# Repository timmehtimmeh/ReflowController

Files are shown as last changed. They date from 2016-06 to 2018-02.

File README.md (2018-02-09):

# TimmehTimmeh's Arduino Board

This repository contains support for the following TimmehTimmeh Arduino-compatible reflow oven controller.  The reflow controller runs on an Atmega32u4 at 3.3V/8MHz.

# Attributions
This project is based on TMK's headless reflow oven (https://github.com/tmk/HeadlessReflowOven) which is in turn based on  work of 

* [ohararp ReflowOven]  (https://github.com/ohararp/ReflowOven)

* which is modification of [rocketscream Reflow-Oven-Controller]  (https://github.com/rocketscream/Reflow-Oven-Controller)

rocketscream released the work under Creative Commons Share Alike v3.0 license.

The bootloader and corresponding installation instructions are a modification of Sparkfun's bootloader code for their Arduino Pro Micro: (https://github.com/sparkfun/Arduino_Boards)

The directory structure is as follows:
* [ReflowBoard]	- The firmware, bootloader, and arduino IDE files that communicate with the board
* [ReflowOven]	- The software (arduino software project) that runs on the board
* [Schematics] - schematics and eagle files for the board
* [libraries] - Library files that the arduino project links against

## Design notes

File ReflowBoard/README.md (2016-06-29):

# TimmehTimmeh's Arduino Board

This repository contains support for the following TimmehTimmeh Arduino-compatible development boards:

#### AVR Boards

* [Tim's Reflow Board]

Each board will be added as an entry to the Arduino **Tools** > **Board** menu.

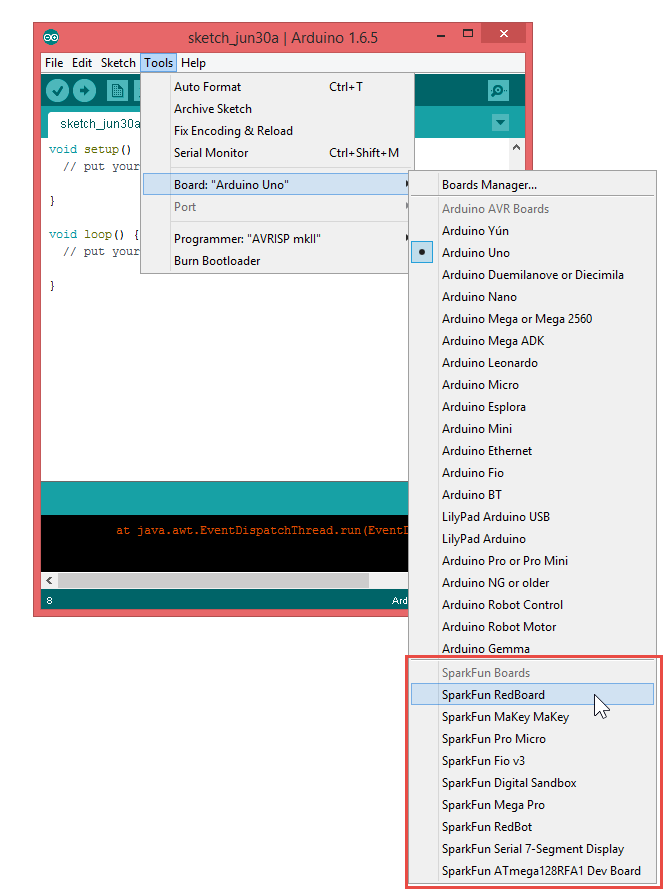
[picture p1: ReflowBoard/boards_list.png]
Example image


### Installation Instructions

To add board support for our products, go to **File** > **Preferences**, and paste this URL into the 'Additional Boards Manager URLs' input field:

	https://raw.githubusercontent.com/timmehtimmeh/ReflowController/master/ReflowBoard/IDE_Board_Manager/package_TimmehTimmeh_index.json

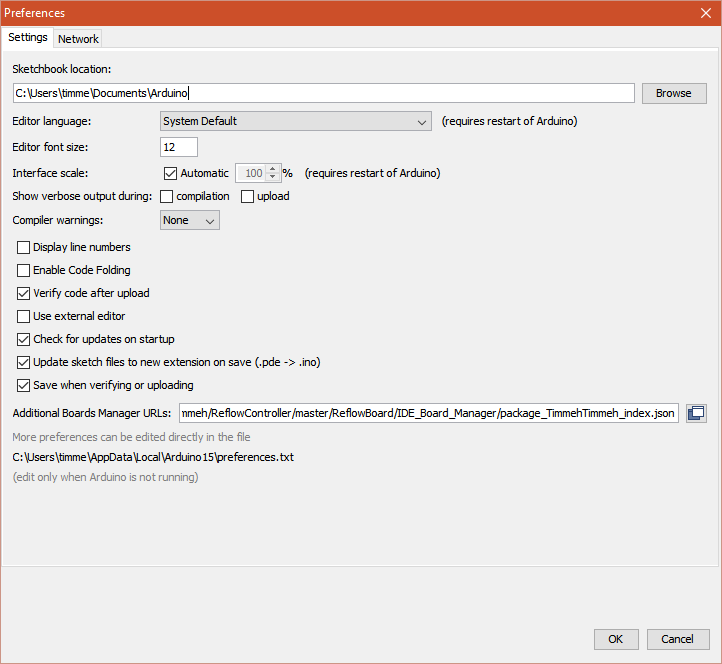
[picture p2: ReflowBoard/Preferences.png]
Adding a board manager list


This field can be found in 'Preferences...' under the Arduino File menu.

Now, under the **Tools** > **Board** > **Boards Manager...**, if you type in "TimmehTimmeh", you will see an option to install board files for the reflow controller board. Click "Install" to add these to your list.

**NOTE: If you are using Arduino 1.6.6 and the link isn't working for you, change "https" at the beginning of the link to "http" and try again. We're working to figure out why this is happening in version 1.6.6.**

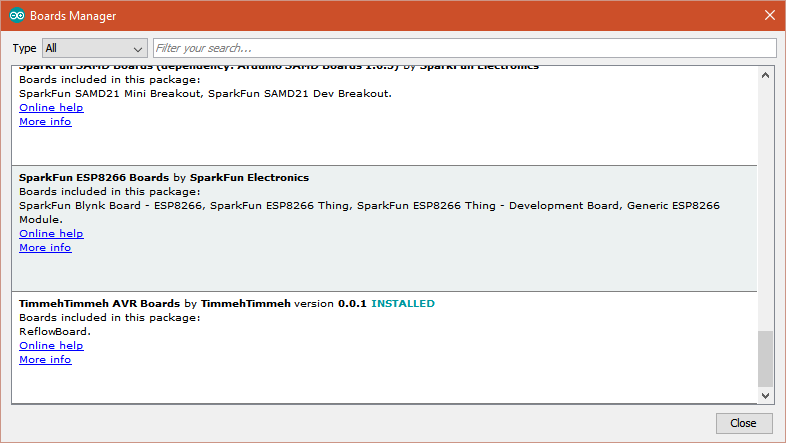
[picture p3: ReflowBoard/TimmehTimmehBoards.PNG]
TimmehTimmeh Boards image


Now, when you select the Boards list, you will see a collection of new boards for Timmeh.

### Flashing the bootloader

To flash the bootloader, power up the board with either the onboard USB or the 2.1mm jack, and plug the board into a AVRISP MKII via the icsp port

In Atmel Studio 
Set the fuses to the  following values:
* low_fuses = 0xFF
* high_fuses = 0xD8
* extended _fuses = 0xFE

### Notes

* **Please note: This will only work under Arduino IDE versions 1.5 and up.**
* Information on compiling and programming the bootloaders can be found in the bootloaders directory.

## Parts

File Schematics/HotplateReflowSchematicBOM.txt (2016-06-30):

Partlist exported from C:/Users/timme/Documents/Arduino/ReflowController/Schematics/HotplateReflowSchematic.sch at 6/29/2016 9:49 PM

Qty Value                        Device                       Package                     Parts                              Description                                                                              MF MPN     OC_FARNELL OC_NEWARK PROD_ID   
1                                LEDCHIP-LED0603              CHIP-LED0603                PWR                                LED                                                                                                                                
1                                M06LOCK                      1X06_LOCK                   JP2                                Header 6                                                                                                                           
1   .1u                          CAP0603-CAP                  0603-CAP                    C7                                 Capacitor                                                                                                                          
1   10k                          RESISTOR0603                 0603-RES                    R6                                 Resistor                                                                                                                           
8   10k                          RESISTOR0603-RES             0603-RES                    R3, R5, R8, R9, R10, R11, R12, R13 Resistor                                                                                                                           
1   10k                          TRIMPOT                      TRIMPOT-5MM-V2              R4                                 Various small potentiometers for "set-and-forget" applications                                                                     
2   10u                          CAP0603-CAP                  0603-CAP                    C2, C10                            Capacitor                                                                                                                          
1   1k                           RESISTOR0603                 0603-RES                    R7                                 Resistor                                                                                                                           
5   1u                           CAP0603-CAP                  0603-CAP                    C1, C3, C4, C8, C9                 Capacitor                                                                                                                          
1   2.1MMJACKTHM                 2.1MMJACKTHM                 PJ-102A                     U$3                                2.1mm x 5.5mm THM DC jack with internal switch. Digikey part #PJ-102A, 4UCON part #05537                                           
2   22                           RESISTOR0603-RES             0603-RES                    R1, R2                             Resistor                                                                                                                           
2   22pF                         CAP0603-CAP                  0603-CAP                    C5, C6                             Capacitor                                                                                                                          
1   47u                          CAP0603-CAP                  0603-CAP                    C11                                Capacitor                                                                                                                          
1   500mA                        PTCFUSE-1812                 1812                        F1                                 PTC fuses, resettable thermistors                                                                                                  
1   8Mhz                         CRYSTALHC49UP                HC49UP                      Q1                                 CRYSTAL                                                                                             unknown    unknown             
1   ATMEGA32U4TQFP               ATMEGA32U4TQFP               SPARKFUN-DIGITALIC_TQFP44   U$1                                Atmel 44-pin 8-bit Microcontroller with 32KBytes of ISP Flash and USB Controller -----                                   IC-11161  
1   JS5208                       JS5208                       JS5208_PKG                  U$2                                                                                                                                                                   
1   JTAG                         M03X2SHROUD                  2X3-SHROUDED                JP1                                2x3 .1" header.                                                                                                          CONN-10681
1   LCD-16X2SILK                 LCD-16X2SILK                 LCD-16X2                    U1                                 Standard text-only 16x2 parallel input LCD                                                                                         
1   LM358D                       LM358D                       SO08                        IC4                                OP AMP also LM158; LM258; LM2904                                                                                                   
1   MAX31855                     MAX31855                     SOIC8                       IC1                                                                                                                                                                   
1   P-CHANNEL-MOSFET-SOT23-3     P-CHANNEL-MOSFET-SOT23-3     SOT23-3                     U$5                                P-Channel MOSFET Mode Field Effect Transistor                                                                                      
2   REG1117                      REG1117                      SOT223                      IC2, IC3                           800mA and 1A Low Dropout (LDO) Positive Regulator                                           REG1117 1097566    14P6981             
2   STANDOFF_ELECTRICAL          STANDOFF_ELECTRICAL          STANDOFF-ELECTRICAL         S2, S4                             A standoff intended to be an electrically connected point.                                                                         
1   SWITCH-MOMENTARY-2SMD-1101NE SWITCH-MOMENTARY-2SMD-1101NE TACTILE-SWITCH-1101NE       S1                                 Various NO switches- pushbuttons, reed, etc                                                                              SWCH-00815
1   Therm                        M022.54MM_SCREWTERM          1X02_2.54_SCREWTERM         JP3                                Standard 2-pin 0.1" header. Use with                                                                                               
1   USB-CON-5PIN-105017-0001     USB-CON-5PIN-105017-0001     USB-MICRO-MOLEX-105017-0001 U$4                                Molex Micro USB 105017-0001

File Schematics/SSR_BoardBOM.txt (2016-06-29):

Partlist exported from C:/Users/timme/Documents/Arduino/ReflowController/Schematics/SSR_Board.sch at 6/28/2016 10:34 PM

Qty Value       Device                Package               Parts              Description                    PROD_ID     VALUE
1               M03SCREW              SCREWTERMINAL-3.5MM-3 JP2                Header 3                                        
1   100         RESISTOR0603-RES      0603-RES              R6                 Resistor                                        
1   10k         RESISTOR0603-RES      0603-RES              R8                 Resistor                                        
1   220         RESISTOR0603-RES      0603-RES              R7                 Resistor                                        
1   2N3904      TRANSISTOR_NPNSOT23-3 SOT23-3               Q2                 Generic NPN BJT                TRANS-08049      
1   330         RESISTOR0603-RES      0603-RES              R5                 Resistor                                        
1   6PCV-02-006 6PCV-02-006           6PCV-02-006           U$2                TE-Connectivity-AMP-Connectors                  
1   GREEN       LED-GREEN0603         LED-0603              D1                 Various green LEDs             DIO-00821   GREEN
1   S108T02     RELAY-SOLIDSTATEPTH   RELAY-S108T02         U1                                                                 
4   STAND-OFF   STAND-OFF             STAND-OFF             U$3, U$4, U$5, U$7 Stand Off

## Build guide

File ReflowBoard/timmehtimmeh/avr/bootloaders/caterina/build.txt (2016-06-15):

make clean
make PID=0x9209 F_CPU=16000000
copy Caterina.hex Caterina-wiflyin.hex
make clean
make PID=0x9207 F_CPU=8000000
copy Caterina.hex Caterina-lilypadusb.hex
make clean
make PID=0x9205 F_CPU=16000000
copy Caterina.hex Caterina-promicro16.hex
make clean
make PID=0x9203 F_CPU=8000000
copy Caterina.hex Caterina-promicro8.hex 
make clean
make PID=0x2B74 F_CPU=16000000
copy Caterina.hex Caterina-makey.hex
make clean
make PID=0xF100 F_CPU=8000000
copy Caterina.hex Caterina-fio.hex
make clean
make PID=0x920B F_CPU=16000000
copy Caterina.hex Caterina-minibench.hex

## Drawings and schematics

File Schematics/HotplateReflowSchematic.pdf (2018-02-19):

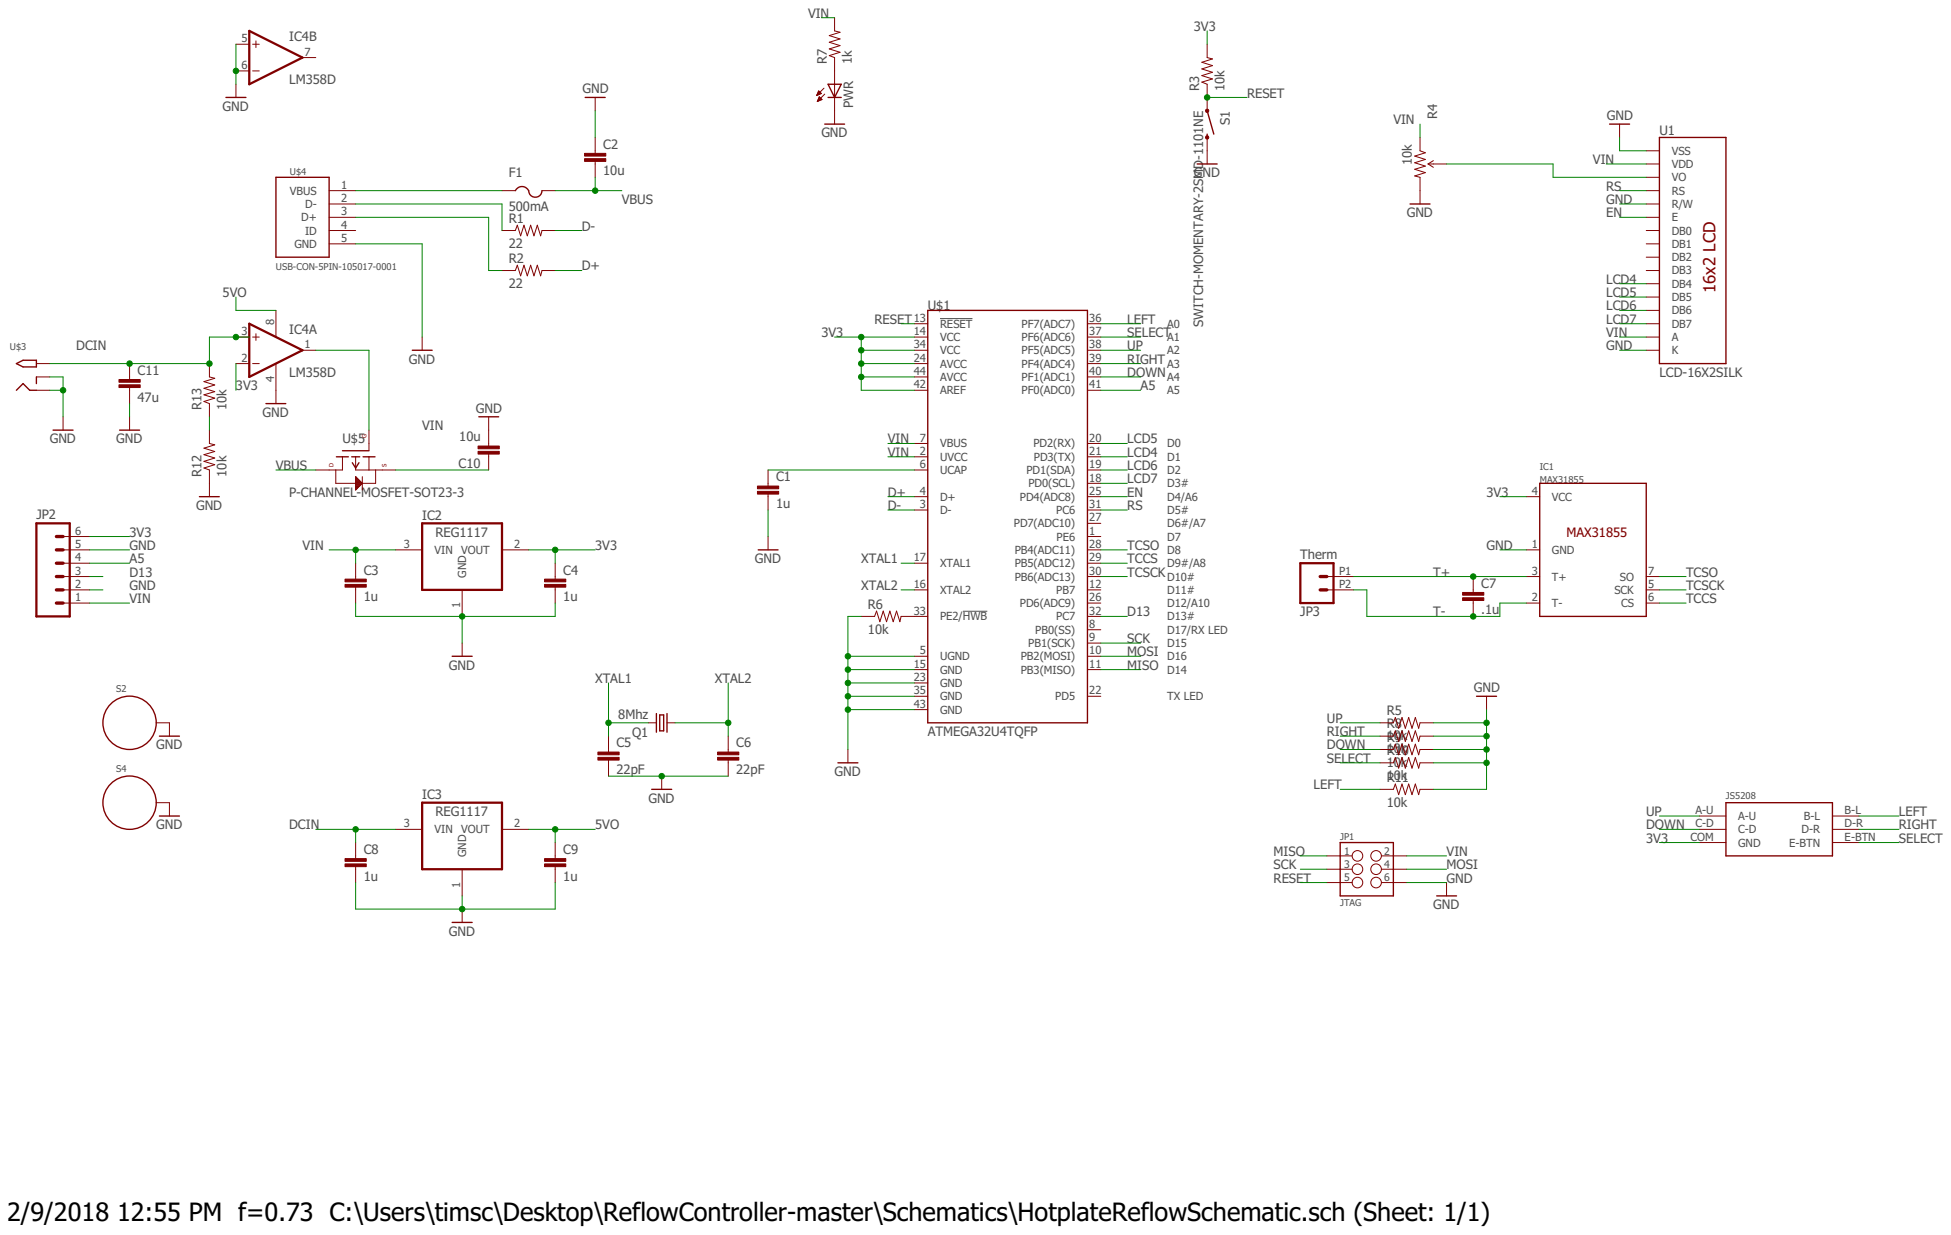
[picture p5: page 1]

2/9/2018 12:55 PM f=0.73 C:\Users\timsc\Desktop\ReflowController-master\Schematics\HotplateReflowSchematic.sch (Sheet: 1/1)

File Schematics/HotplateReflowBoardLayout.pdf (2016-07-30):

1
500mA MAX3185 | REG¹¹¹⁷

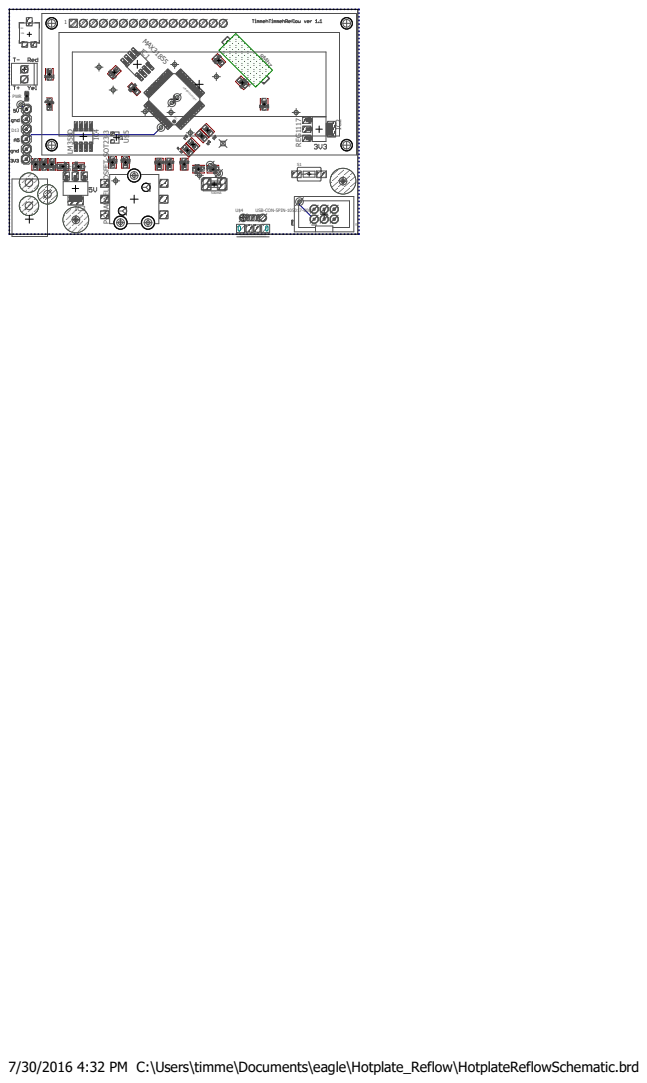
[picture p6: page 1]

8Mhz 10k ATMEGA32U4TQFP USB-CON-5PIN-105017-0001 P-CHANNEL-MOSFET-SOT23-3 LM358D

PCB EDGE CONNECTOR FRONT INTERFACE

7/30/2016 4:32 PM C:\Users\timme\Documents\eagle\Hotplate_Reflow\HotplateReflowSchematic.brd

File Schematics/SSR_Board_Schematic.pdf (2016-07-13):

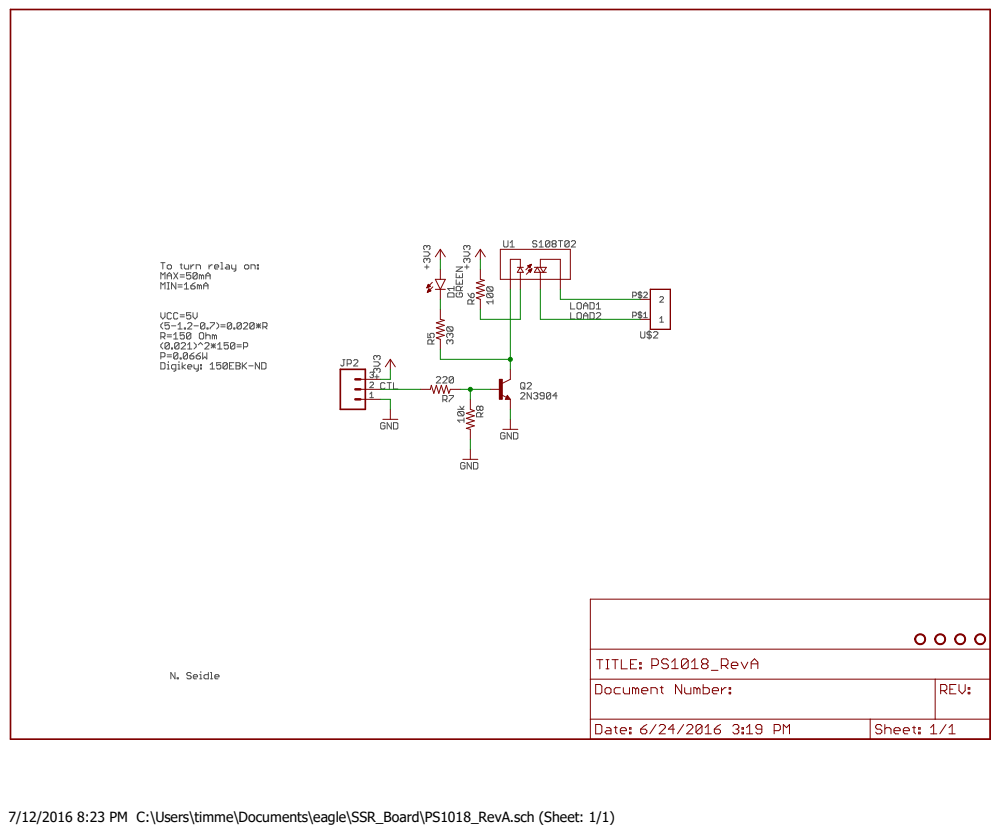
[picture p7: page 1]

7/12/2016 8:23 PM C:\Users\timme\Documents\eagle\SSR_Board\PS1018_RevA.sch (Sheet: 1/1)

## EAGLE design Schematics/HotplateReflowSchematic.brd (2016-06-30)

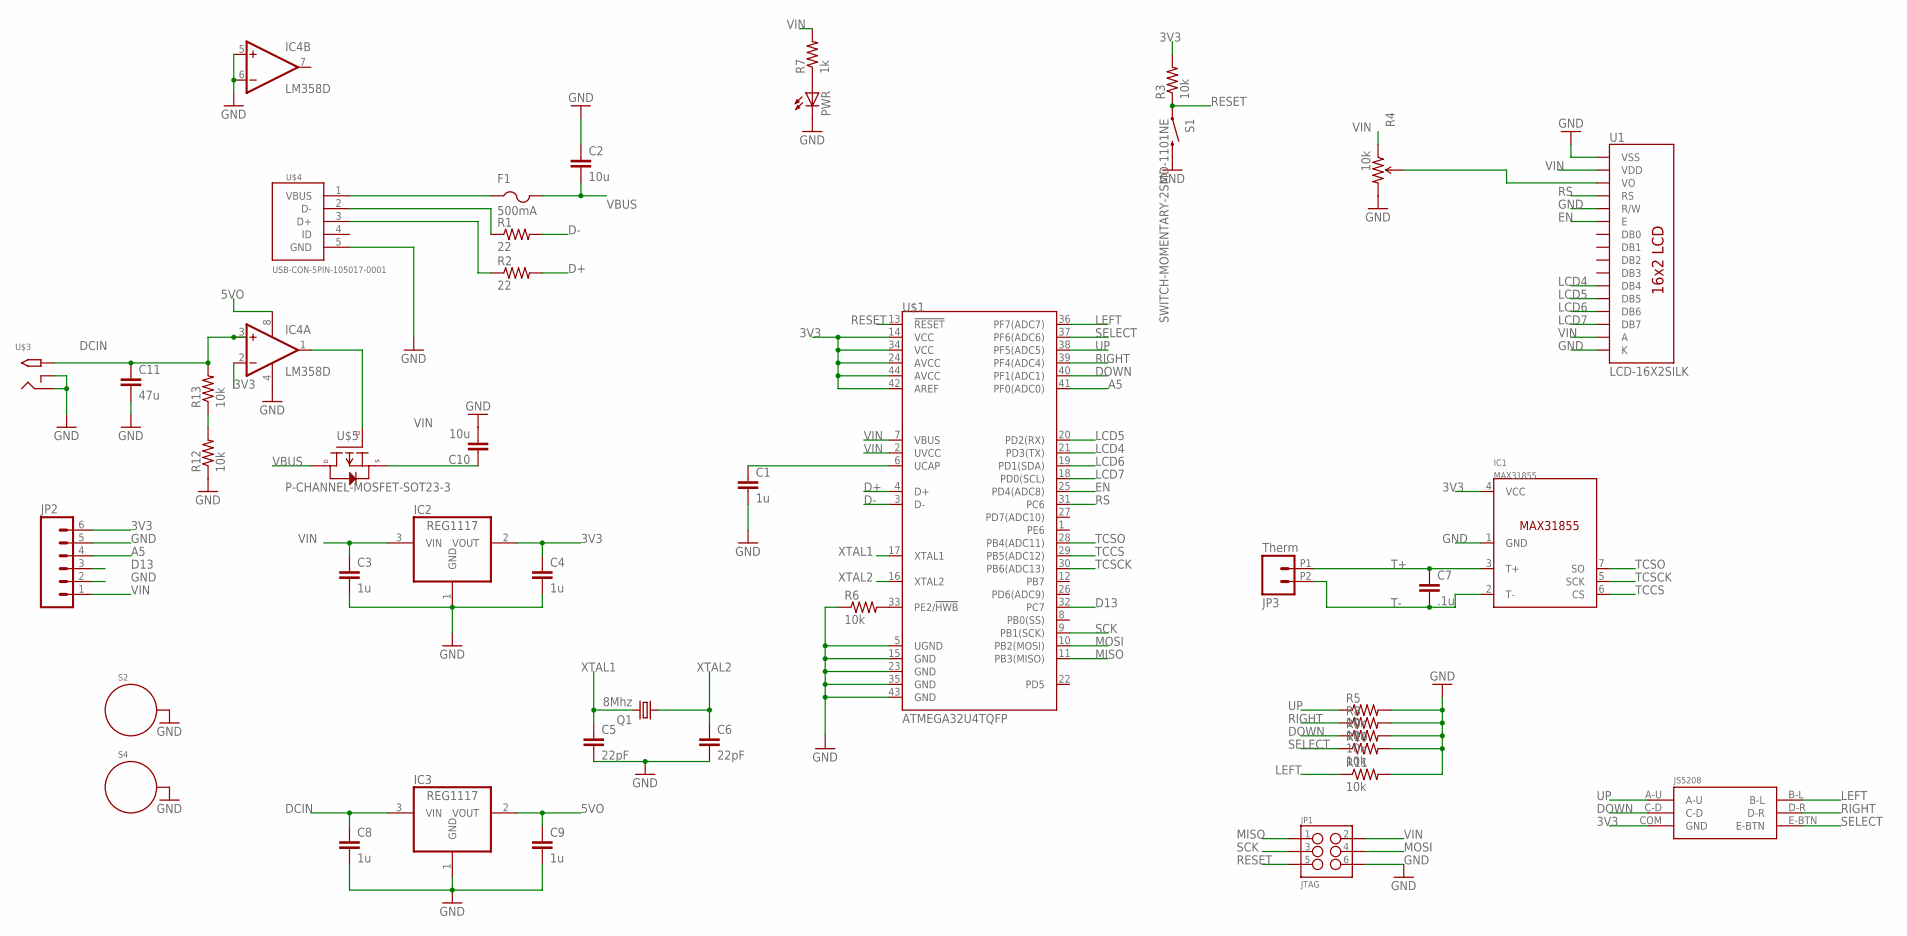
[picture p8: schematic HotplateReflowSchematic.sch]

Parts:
C1, C3, C4, C8, C9: 1u; 0603-CAP
C2, C10: 10u; 0603-CAP
C5, C6: 22pF; 0603-CAP
C7: .1u; 0603-CAP
C11: 47u; 0603-CAP
F1: 500mA; 1812
IC1: MAX31855; SOIC8
IC2, IC3: REG1117; SOT223
IC4: LM358D; SO08
JP1: JTAG; 2X3-SHROUDED
JP2: M06LOCK; 1X06_LOCK
JP3: Therm; 1X02_2.54_SCREWTERM
PWR: LEDCHIP-LED0603; CHIP-LED0603
Q1: 8Mhz; HC49UP
R1, R2: 22; 0603-RES
R3, R5, R6, R8, R9, R10, R11, R12, R13: 10k; 0603-RES
R4: 10k; TRIMPOT-5MM-V2
R7: 1k; 0603-RES
S1: SWITCH-MOMENTARY-2SMD-1101NE; TACTILE-SWITCH-1101NE
S2, S4: STANDOFF_ELECTRICAL; STANDOFF-ELECTRICAL
U1: LCD-16X2SILK; LCD-16X2
U$1: ATMEGA32U4TQFP; SPARKFUN-DIGITALIC_TQFP44
U$2: JS5208; JS5208_PKG
U$3: 2.1MMJACKTHM; PJ-102A
U$4: USB-CON-5PIN-105017-0001; USB-MICRO-MOLEX-105017-0001
U$5: P-CHANNEL-MOSFET-SOT23-3; SOT23-3

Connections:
3V3: C4.1, IC1.4 (VCC), IC2.2 (VOUT), IC4.2 (-IN), JP2.6, R3.2, U$1.14 (VCC), U$1.24 (AVCC), U$1.34 (VCC), U$1.42 (AREF), U$1.44 (AVCC), U$2.COM (GND)
5VO: C9.1, IC3.2 (VOUT), IC4.8 (V+)
A5: JP2.4, U$1.41 (PF0(ADC0))
D13: JP2.3, U$1.32 (PC7)
D+: R2.2, U$1.4 (D+)
D-: R1.2, U$1.3 (D-)
DCIN: C8.1, C11.1, IC3.3 (VIN), IC4.3 (+IN), R13.2, U$3.TIP
DOWN: R9.1, U$1.40 (PF1(ADC1)), U$2.C-D
EN: U1.6 (E), U$1.25 (PD4(ADC8))
GND: C1.2, C2.1, C3.2, C4.2, C5.2, C6.2, C8.2, C9.2, C10.2, C11.2, IC1.1 (GND), IC2.1 (GND), IC3.1 (GND), IC4.4 (V-), IC4.5 (+IN), IC4.6 (-IN), JP1.6, JP2.2, JP2.5, PWR.C, R4.C (CW), R5.2, R6.1, R8.2, R9.2, R10.2, R11.2, R12.1, S1.2, S2.P1, S4.P1, U1.1 (VSS), U1.5 (R/W), U1.16 (K), U$1.5 (UGND), U$1.15 (GND), U$1.23 (GND), U$1.35 (GND), U$1.43 (GND), U$3.RING, U$3.RING_SW, U$4.5 (GND)
LCD4: U1.11 (DB4), U$1.21 (PD3(TX))
LCD5: U1.12 (DB5), U$1.20 (PD2(RX))
LCD6: U1.13 (DB6), U$1.19 (PD1(SDA))
LCD7: U1.14 (DB7), U$1.18 (PD0(SCL))
LEFT: R11.1, U$1.36 (PF7(ADC7)), U$2.B-L
MISO: JP1.1, U$1.11 (PB3(MISO))
MOSI: JP1.4, U$1.10 (PB2(MOSI))
unnamed: R4.B (WIPER), U1.3 (VO)
unnamed: F1.1, U$4.1 (VBUS)
unnamed: R1.1, U$4.2 (D-)
unnamed: R2.1, U$4.3 (D+)
unnamed: C1.1, U$1.6 (UCAP)
unnamed: PWR.A, R7.1
unnamed: R6.2, U$1.33 (PE2/!HWB)
unnamed: R12.2, R13.1
unnamed: IC4.1 (OUT), U$5.1 (G)
RESET: JP1.5, R3.1, S1.1, U$1.13 (!RESET)
RIGHT: R8.1, U$1.39 (PF4(ADC4)), U$2.D-R
RS: U1.4 (RS), U$1.31 (PC6)
SCK: JP1.3, U$1.9 (PB1(SCK))
SELECT: R10.1, U$1.37 (PF6(ADC6)), U$2.E-BTN
T+: C7.1, IC1.3 (T+), JP3.P1 (1)
T-: C7.2, IC1.2 (T-), JP3.P2 (2)
TCCS: IC1.6 (CS), U$1.29 (PB5(ADC12))
TCSCK: IC1.5 (SCK), U$1.30 (PB6(ADC13))
TCSO: IC1.7 (SO), U$1.28 (PB4(ADC11))
UP: R5.1, U$1.38 (PF5(ADC5)), U$2.A-U
VBUS: C2.2, F1.2, U$5.3 (D)
VIN: C3.1, C10.1, IC2.3 (VIN), JP1.2, JP2.1, R4.A (CCW), R7.2, U1.2 (VDD), U1.15 (A), U$1.2 (UVCC), U$1.7 (VBUS), U$5.2 (S)
XTAL1: C5.1, Q1.2, U$1.17 (XTAL1)
XTAL2: C6.1, Q1.1, U$1.16 (XTAL2)

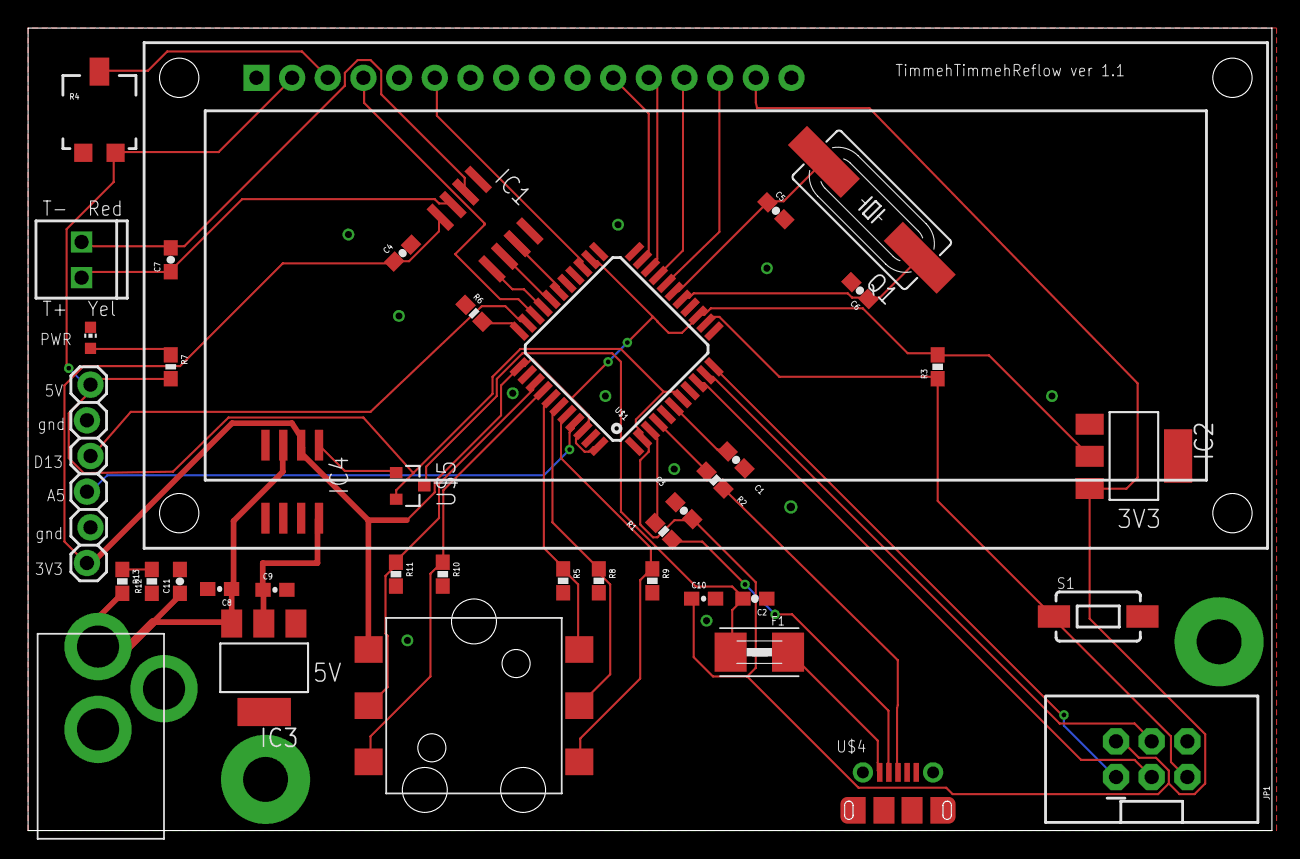
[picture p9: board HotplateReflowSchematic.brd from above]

Board: 2 copper layers, 88.6 x 57.1 mm, 43 parts (0 on the bottom side), 41 nets.

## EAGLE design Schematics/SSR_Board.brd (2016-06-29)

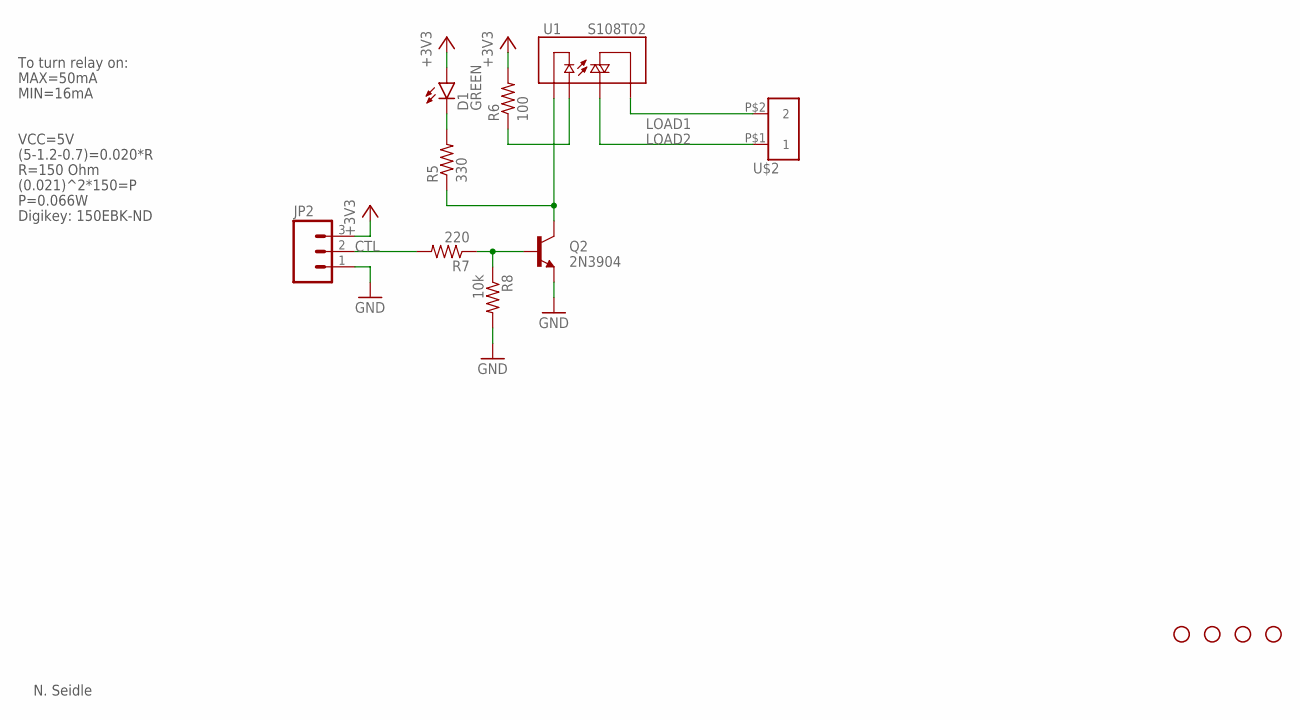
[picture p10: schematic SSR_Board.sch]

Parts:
D1: GREEN; LED-0603
JP2: M03SCREW; SCREWTERMINAL-3.5MM-3
Q2: 2N3904; SOT23-3
R5: 330; 0603-RES
R6: 100; 0603-RES
R7: 220; 0603-RES
R8: 10k; 0603-RES
U1: S108T02; RELAY-S108T02
U$2: 6PCV-02-006
U$3, U$4, U$5, U$7: STAND-OFF

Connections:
+3V3: D1.A, JP2.3, R6.2
COIL: Q2.3 (C), R5.1, U1.4 (-)
CTL: JP2.2, R7.2
GND: JP2.1, Q2.2 (E), R8.2
LOAD1: U1.1 (T1), U$2.P$2 (2)
LOAD2: U1.2 (T2), U$2.P$1 (1)
unnamed: R6.1, U1.3 (+)
unnamed: Q2.1 (B), R7.1, R8.1
unnamed: D1.C, R5.2

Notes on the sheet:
N. Seidle
To turn relay on:
(5-1.2-0.7)=0.020*R
R=150 Ohm
VCC=5V
MAX=50mA
MIN=16mA
(0.021)^2*150=P
P=0.066W
Digikey: 150EBK-ND

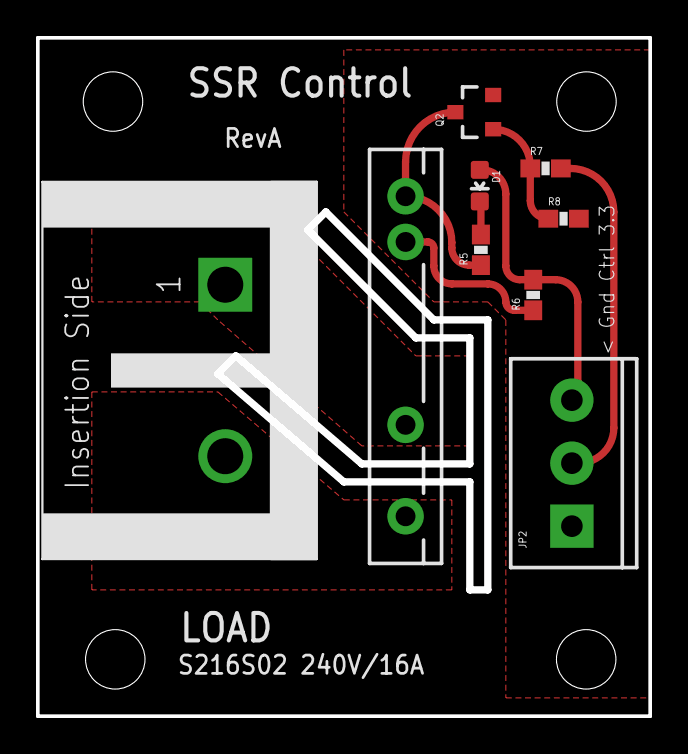
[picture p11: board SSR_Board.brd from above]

Board: 2 copper layers, 34.0 x 37.7 mm, 13 parts (0 on the bottom side), 9 nets.

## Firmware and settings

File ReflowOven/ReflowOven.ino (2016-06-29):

/*********************************************************************
  Headless ReflowController - just with button, buzzer and LED

  based on ReflowOven
    https://github.com/ohararp/ReflowOven

  - To start/abort reflow process push button.
  - Buzzer beeps when cooling stage starts and ends. You may open door oven to cool quickly.
  - LED and buzzer are optional but buzzer is recommended.
  - Using with KOIZUMI Wide Oven Toaster 1200W KOS-1202
**********************************************************************/
// Includes
#include <Adafruit_MAX31855.h>  // Thermocouple Library - https://github.com/rocketscream/MAX31855
#include <PID_v1.h>             // PID Library - http://playground.arduino.cc/Code/PIDLibrary
//             - https://github.com/br3ttb/Arduino-PID-Library/
#include <LiquidCrystal.h>


typedef enum REFLOW_STATE
{
  REFLOW_STATE_IDLE,
  REFLOW_STATE_PREHEAT,
  REFLOW_STATE_SOAK,
  REFLOW_STATE_REFLOW,
  REFLOW_STATE_COOL,
  REFLOW_STATE_COMPLETE,
  REFLOW_STATE_TOO_HOT,
  REFLOW_STATE_ERROR,
  REFLOW_STATE_ABORT
} reflowState_t;

typedef enum REFLOW_STATUS
{
  REFLOW_STATUS_OFF,
  REFLOW_STATUS_ON
} reflowStatus_t;

typedef enum MENU_STATE
{
  MENU_START_SELECTED,
  MENU_PREHEAT_PARAMS_SELECTED,
  MENU_SET_PREHEAT_PARAMS,
  MENU_SOAK_PARAMS_SELECTED,
  MENU_SET_SOAK_PARAMS,
  MENU_REFLOW_PARAMS_SELECTED,
  MENU_SET_REFLOW_PARAMS,
  MENU_COOL_PARAMS_SELECTED,
  MENU_SET_COOL_PARAMS,
  MENU_STATE_REFLOWING
} menuState_t;


/*  Reflow temperature profile

    Tamura leaded SOLDER PASTE(Sn62.8 Pb36.8 Ag0.4) Reflow Profile
        |
    220-|                                                  x  x
        |                                                x       x
    200-|                                               x           x
        |                                              x|           |
        |                                            x  |           | x
    170-|                              x x x  x x  x    |           |   x
        |                  x  x  x  x           |       |<- 20-60s->|     x
    150-|               x                       |                   |
        |             x |                       |                   |
        |           x   |                       |                   |
        |         x     |                       |                   |
        |       x       |                       |                   |
        |     x         |                       |                   |
        |   x   <3C/s   |        20C/60s        |         20/20s    |
    30 -| x             |                       |                   |
        |     <60s      |<-        60s        ->|                   |
        |     Preheat   |        Soaking        |       Reflow      |   Cool
     0  |_ _ _ _ _ _ _ _|_ _ _ _ _ _ _ _ _ _ _ _|_ _ _ _ _ _ _ _ _ _|_ _ _ _
*/
float TEMPERATURE_COOL       = 100;
float TEMPERATURE_SOAK_MIN   = 150;
float TEMPERATURE_SOAK_MAX   = 170;
float TEMPERATURE_REFLOW_MAX = 230;

// Preheat: 1.5C/s
#define PREHEAT_TEMPERATURE_STEP    15
#define PREHEAT_MS_STEP             10000

// Soak: 20C/60s
#define SOAK_TEMPERATURE_STEP       2
#define SOAK_MS_STEP                6000

// Reflow: 20C/20s
#define REFLOW_TEMPERATURE_STEP     5
#define REFLOW_MS_STEP              5000


// ***** PID PARAMETERS *****
// ***** PRE-HEAT STAGE *****
float PID_KP_PREHEAT         = 300;
float PID_KI_PREHEAT         = 0.05;
float PID_KD_PREHEAT         = 350;
// ***** SOAKING STAGE *****
float PID_KP_SOAK            = 300;
float PID_KI_SOAK            = 0.05;
float PID_KD_SOAK            = 350;
// ***** REFLOW STAGE *****
float PID_KP_REFLOW          = 300;
float PID_KI_REFLOW          = 0.05;
float PID_KD_REFLOW          = 350;

#define PID_SAMPLE_TIME        1000
#define SENSOR_SAMPLING_TIME   1000


// Reflow status strings
const char* ssdMessagesReflowStatus[] = {
  "  Ready  ",
  " Preheat ",
  "   Soak  ",
  "  Reflow ",
  "   Cool  ",
  " Complete",
  "  !HOT!  ",
  "  Error  "
};


//
// Pin Definitions
//

int noPin = -1;
int upPin = A2;
int downPin = A4;
int leftPin = A0;
int rightPin = A3;
int selectPin = A1;

int HeaterPin = 13;
int SSRPin1 = A5;

int thermocoupleCLKPin = 10;
int thermocoupleSOPin  = 8;
int thermocoupleCSPin  = 9;

LiquidCrystal lcd(5, 4, 1, 0, 2, 3);

// ***** PID CONTROL VARIABLES *****
double setpoint;
double input;
double inputOld; //Store old Temperature

double output;
double kp = PID_KP_PREHEAT;
double ki = PID_KI_PREHEAT;
double kd = PID_KD_PREHEAT;
int windowSize;
unsigned long windowStartTime;
unsigned long nextCheck;
unsigned long nextRead;
unsigned long timerSoak;
unsigned long buzzerPeriod;
boolean StartTest;

// Reflow oven controller state machine state variable
reflowState_t reflowState;
// Reflow oven controller status
reflowStatus_t reflowStatus;

menuState_t menuState;

//Button Variables
byte ButtCount  = 0;

// tc Error Counter
int tcErrorCtr = 0;

// Seconds timer
int timerSeconds;

// Library Setup
// Specify PID control interface
PID reflowOvenPID(&input, &output, &setpoint, kp, ki, kd, DIRECT);
Adafruit_MAX31855 thermocouple(thermocoupleCLKPin, thermocoupleCSPin, thermocoupleSOPin);

// Setup
void setup()   {
  // Setup Serial Baudrate
  Serial.begin(57600);

  // set up the LCD's number of columns and rows:
  lcd.begin(16, 2);
  lcd.print("Hello World");

  // initialize the Led pin as an output.
  //pinMode(Led, OUTPUT);

  // Init Buttons
  // pinMode(selectPin, INPUT_PULLUP);

  // Init Elements
  pinMode(HeaterPin, OUTPUT);
  //pinMode(BuzPin, OUTPUT);

  digitalWrite(HeaterPin, LOW);
  //digitalWrite(BuzPin, LOW);

  //button pin setup
  pinMode(selectPin, INPUT);
  pinMode(upPin, INPUT);
  pinMode(downPin, INPUT);
  pinMode(leftPin, INPUT);
  pinMode(rightPin, INPUT);

  //output pins to control relay
  //pinMode(SSRPin0, OUTPUT);
  pinMode(SSRPin1, OUTPUT);

  // Set window size
  windowSize = 5000;
  // Initialize time keeping variable
  nextCheck = millis();
  // Initialize thermocouple reading variable
  nextRead = millis();
  // Set Relow Status = OFF
  reflowStatus = REFLOW_STATUS_OFF;
  menuState = MENU_START_SELECTED;

  StartTest = false;
}

void PrintMenuOptions(bool leftPin, bool rightPin, bool upPin, bool downPin, bool selectPin) {

  Serial.print(leftPin);
  Serial.print(rightPin);
  Serial.print(upPin);
  Serial.print(downPin);
  Serial.println(selectPin);

  //  MENU_START_SELECTED,
  //  MENU_PREHEAT_PARAMS_SELECTED,
  //  MENU_SET_PREHEAT_PARAMS,
  //  MENU_SOAK_PARAMS_SELECTED,
  //  MENU_SET_SOAK_PARAMS,
  //  MENU_REFLOW_PARAMS_SELECTED,
  //  MENU_SET_REFLOW_PARAMS,
  //  MENU_COOL_PARAMS_SELECTED,
  //  MENU_SET_COOL_PARAMS,
  //  MENU_STATE_REFLOWING

  if (millis() > nextRead)
  {
    // Read thermocouple next sampling period
    nextRead += SENSOR_SAMPLING_TIME;
    input = thermocouple.readCelsius();
    lcd.setCursor(11, 1);
    lcd.print(input);
  }
  switch (menuState)
  {

    case MENU_START_SELECTED:
      lcd.setCursor(0, 0);
      lcd.print("Cool >Start  Preheat");

      if (leftPin) {
        menuState = MENU_COOL_PARAMS_SELECTED;
      } else if (rightPin) {
        menuState = MENU_PREHEAT_PARAMS_SELECTED;
      }
      else if (selectPin) {
        menuState = MENU_STATE_REFLOWING;
        StartTest = true;
      }
      break;
    case MENU_PREHEAT_PARAMS_SELECTED:
      lcd.setCursor(0, 0);
      lcd.print("Start >Preheat  Soak");

      if (leftPin) {
        menuState = MENU_START_SELECTED;
      } else if (rightPin) {
        menuState = MENU_SOAK_PARAMS_SELECTED;
      } else if (selectPin || upPin || downPin) {
        menuState = MENU_SET_PREHEAT_PARAMS;
      }
      //      else if (upPin || downPin) {
      //        menuState = MENU_START_SELECTED;
      //      }

      break;
    case MENU_SOAK_PARAMS_SELECTED:
      lcd.setCursor(0, 0);
      lcd.print("Preheat >Soak Reflow");

      if (leftPin) {
        menuState = MENU_PREHEAT_PARAMS_SELECTED;
      } else if (rightPin) {
        menuState = MENU_REFLOW_PARAMS_SELECTED;
      } else if (selectPin || upPin || downPin) {
        menuState = MENU_SET_SOAK_PARAMS;
      }
      //      else if (upPin || downPin) {
      //        menuState = MENU_START_SELECTED;
      //      }
      break;
    case MENU_REFLOW_PARAMS_SELECTED:
      lcd.setCursor(0, 0);
      lcd.print("Soak >Reflow Cool");

      if (leftPin) {
        menuState = MENU_SOAK_PARAMS_SELECTED;
      } else if (rightPin) {
        menuState = MENU_COOL_PARAMS_SELECTED;
      } else if (selectPin || upPin || downPin) {
        menuState = MENU_SET_REFLOW_PARAMS;
      }
      //      else if (upPin || downPin) {
      //        menuState = MENU_START_SELECTED;
      //      }
      break;
    case MENU_COOL_PARAMS_SELECTED:
      lcd.setCursor(0, 0);
      lcd.print("Reflow >Cool  Start");

      if (leftPin) {
        menuState = MENU_REFLOW_PARAMS_SELECTED;
      } else if (rightPin) {
        menuState = MENU_START_SELECTED;
      } else if (selectPin || upPin || downPin) {
        menuState = MENU_SET_COOL_PARAMS;
      }
      //      else if (upPin || downPin) {
      //        menuState = MENU_START_SELECTED;
      //      }
      break;

    //TEMP SETTINGS
    //        float TEMPERATURE_COOL       = 100;
    //        float TEMPERATURE_SOAK_MIN   = 150;
    //        float TEMPERATURE_SOAK_MAX   = 170;
    //        float TEMPERATURE_REFLOW_MAX = 230;

    case MENU_SET_PREHEAT_PARAMS:
      lcd.setCursor(0, 0);
      lcd.print("Preheat Max     Curr");
      lcd.setCursor(0, 1);
      lcd.print(TEMPERATURE_SOAK_MIN);

      if (leftPin || downPin) {
        TEMPERATURE_SOAK_MIN -= 5;
      } else if (rightPin || upPin) {
        TEMPERATURE_SOAK_MIN += 5;
      } else if (selectPin  ) {
        menuState = MENU_PREHEAT_PARAMS_SELECTED;
      }
      break;
    case MENU_SET_SOAK_PARAMS:
      lcd.setCursor(0, 0);
      lcd.print("Soak Max     Curr");
      lcd.setCursor(0, 1);
      lcd.print(TEMPERATURE_SOAK_MAX);

      if (leftPin || downPin) {
        TEMPERATURE_SOAK_MAX -= 5;
      } else if (rightPin || upPin) {
        TEMPERATURE_SOAK_MAX += 5;
      } else if (selectPin || upPin || downPin) {
        menuState = MENU_SOAK_PARAMS_SELECTED;
      }
      break;
    case MENU_SET_REFLOW_PARAMS:
      lcd.setCursor(0, 0);
      lcd.print("Reflow Max     Curr");
      lcd.setCursor(0, 1);
      lcd.print(TEMPERATURE_REFLOW_MAX);

      if (leftPin || downPin) {
        TEMPERATURE_REFLOW_MAX -= 5;
      } else if (rightPin || upPin) {
        TEMPERATURE_REFLOW_MAX += 5;
      } else if (selectPin || upPin || downPin) {
        menuState = MENU_REFLOW_PARAMS_SELECTED;
      }
      break;
    case MENU_SET_COOL_PARAMS:
      lcd.setCursor(0, 0);
      lcd.print("Cool To     Curr");
      lcd.setCursor(0, 1);
      lcd.print(TEMPERATURE_COOL);

      if (leftPin || downPin) {
        TEMPERATURE_COOL -= 5;
      } else if (rightPin || upPin) {
        TEMPERATURE_COOL += 5;
      } else if (selectPin || upPin || downPin) {
        menuState = MENU_COOL_PARAMS_SELECTED;
      }
      break;
  }


}


//returns true if pin is held high for longer than 50ms
bool debounceButton(int pin) {

  bool ret = false;
  int count = 0;

  for (int i = 0; i < 5; i++) {
    if (digitalRead(pin) == HIGH)
    {
      count++;
      delay(20);
    }
  }

  if (count >= 4)
  {
    ret = true;
  } else
  {
    ret = false;
  }

  return ret;
}


// Begin Main Loop
void loop()
{
  // Current time
  unsigned long now;

  if (menuState != MENU_STATE_REFLOWING) {

    //now read from the joystick
    if (digitalRead(leftPin) == HIGH)
    {
      if (debounceButton(leftPin)) {
        //left, right, up, down, select
        PrintMenuOptions(true, false, false, false, false);
      }
    }

    if (digitalRead(rightPin) == HIGH)
    {
      if (debounceButton(rightPin)) {
        //left, right, up, down, select
        PrintMenuOptions(false, true, false, false, false);
      }
    }
    else if (digitalRead(upPin) == HIGH)
    {
      if (debounceButton(upPin)) {
        //left, right, up, down, select
        PrintMenuOptions(false, false, true, false, false);
      }
    }
    else if (digitalRead(downPin) == HIGH)
    {
      if (debounceButton(downPin)) {
        //left, right, up, down, select
        PrintMenuOptions(false, false, false, true, false);
      }
    }
    else if (digitalRead(selectPin) == HIGH)
    {
      //left, right, up, down, select
      if (debounceButton(selectPin)) {
        PrintMenuOptions(false, false, false, false, true);
      }
    } else {
      PrintMenuOptions(false, false, false, false, false);
      return;
    }
  } else { //menu state is reflowing
    // Test for Abort Button Input
    if (digitalRead(selectPin) == HIGH)
    {
      if (debounceButton(selectPin)) {
        //tone(BuzPin,4100,500); //Buzz the Buzzer
        while (digitalRead(selectPin) != LOW) ;
        reflowState = REFLOW_STATE_IDLE;


        if (reflowStatus == REFLOW_STATUS_ON) {
          reflowState = REFLOW_STATE_ABORT;
          menuState = MENU_START_SELECTED;
          StartTest = false;
        } else {

        }
      }
      else
      {
        ButtCount = 0;
        StartTest = false;
        menuState = MENU_START_SELECTED;
      }
    }
  }

  //********************************************************************************************************
  // Time to read thermocouple?
  if (millis() > nextRead)
  {
    // Read thermocouple next sampling period
    nextRead += SENSOR_SAMPLING_TIME;
    // Read current temperature
    inputOld = input; //Store Old Temperature
    input = thermocouple.readCelsius();

    if (isnan(input))
    {
      input = inputOld;
      tcErrorCtr++;

      if (tcErrorCtr >= 5)
      {
        // Illegal operation
        reflowState  = REFLOW_STATE_ERROR;
        reflowStatus = REFLOW_STATUS_OFF;
      }
    }
    else
    {
      tcErrorCtr = 0;
    }
  }

  if (millis() > nextCheck)
  {
    lcd.clear();
    // Check input in the next seconds
    nextCheck += 1000;
    // If reflow process is on going
    if (reflowStatus == REFLOW_STATUS_ON)
    {
      // Toggle LED as system heart beat
      //digitalWrite(Led, !(digitalRead(Led)));
      // Increase seconds timer for reflow curve analysis
      timerSeconds++;
      // Send temperature and time stamp to serial
      Serial.print(timerSeconds);
      Serial.print(",");
      //Serial.print(thermocouple.readInternal());
      //Serial.print(",");
      Serial.print(setpoint);
      Serial.print(",");
      Serial.print(input);
      Serial.print(",");
      Serial.print(output);
      Serial.print(",");
      Serial.println(ssdMessagesReflowStatus[reflowState]);
      //lcd.clear();
      //      lcd.setCursor(0, 0);
      //      lcd.print("Reflow Status On");
      //      lcd.setCursor(11,1);
      //      lcd.print(input);
    }
    else
    {
      Serial.print(input);
      Serial.print(" ");
      Serial.print(thermocouple.readInternal());
      Serial.print(" ");
      Serial.println(thermocouple.readCelsius());
      // Turn off LED
      //digitalWrite(Led, HIGH);
      //lcd.clear();
      //lcd.setCursor(0, 0);
      //lcd.print("Reflow Off");
      //lcd.setCursor(11, 1);
      //lcd.print(input);
    }

    // If currently in error state
    if (reflowState == REFLOW_STATE_ERROR)
    {
      // No thermocouple wire conLednected
      Serial.print("TC Error!\n");

      lcd.setCursor(0, 0);
      lcd.print("TC Error");
      lcd.setCursor(11, 1);
      lcd.print(input);
    }
  }






  // Reflow oven controller state machine
  switch (reflowState)
  {
    case REFLOW_STATE_IDLE:
      // If oven temperature is still above room temperature
      if (input >= TEMPERATURE_COOL)
      {
        reflowState = REFLOW_STATE_TOO_HOT;

        Serial.print(" - HOT - ");
        Serial.println(input);

        //lcd.clear();
        lcd.setCursor(0, 0);
        lcd.print(" - HOT - ");
        lcd.setCursor(11, 1);
        lcd.print(input);
      }
      else
      {
        if (StartTest == true)
        {
          Serial.println(" - Begin  - ");
          //lcd.clear();
          lcd.setCursor(0, 0);
          lcd.print(" - Begin  - ");

          //Serial.println("Time Setpoint Input Output");
          timerSeconds = 0;

          // Initialize PID control window starting time
          windowStartTime = millis();

          // Tell the PID to range between 0 and the full window size
          reflowOvenPID.SetOutputLimits(0, windowSize);
          reflowOvenPID.SetSampleTime(PID_SAMPLE_TIME);
          reflowOvenPID.SetMode(AUTOMATIC);

          // Preheat profile
          setpoint = input + PREHEAT_TEMPERATURE_STEP;
          timerSoak = millis() + PREHEAT_MS_STEP;

          // Proceed to preheat stage
          reflowState = REFLOW_STATE_PREHEAT;
          StartTest = false;
        }
      }
      break;

    case REFLOW_STATE_PREHEAT:
      //lcd.clear();
      lcd.setCursor(0, 0);
      lcd.print("Preheating");

      if (timerSeconds / 100 != 0)
        lcd.setCursor(13, 0);
      else if (timerSeconds / 10 != 0)
        lcd.setCursor(14, 0);
      else
        lcd.setCursor(15, 0);
      lcd.print(timerSeconds);

      lcd.setCursor(0, 1);
      lcd.print(setpoint);

      lcd.setCursor(11, 1);
      lcd.print(input);

      reflowStatus = REFLOW_STATUS_ON;
      if (millis() > timerSoak)
      {
        setpoint = input + PREHEAT_TEMPERATURE_STEP;
        if (setpoint > TEMPERATURE_SOAK_MIN) setpoint = TEMPERATURE_SOAK_MIN;
        timerSoak = millis() + PREHEAT_MS_STEP;

        // If minimum soak temperature is achieve
        if (input >= TEMPERATURE_SOAK_MIN - 2.5)
        {
          reflowOvenPID.SetTunings(PID_KP_SOAK, PID_KI_SOAK, PID_KD_SOAK);
          setpoint = TEMPERATURE_SOAK_MIN + SOAK_TEMPERATURE_STEP;
          timerSoak = millis() + SOAK_MS_STEP;

          // Proceed to soaking state
          reflowState = REFLOW_STATE_SOAK;
        }
      }
      break;

    case REFLOW_STATE_SOAK:
      //lcd.clear();
      lcd.setCursor(0, 0);
      lcd.print("Soaking");

      lcd.setCursor(11, 1);
      lcd.print(input);
      // If micro soak temperature is achieved
      if (millis() > timerSoak)
      {
        timerSoak = millis() + SOAK_MS_STEP;
        // Increment micro setpoint
        setpoint += SOAK_TEMPERATURE_STEP;
        if (setpoint > TEMPERATURE_SOAK_MAX)
        {
          // Set agressive PID parameters for reflow ramp
          reflowOvenPID.SetTunings(PID_KP_REFLOW, PID_KI_REFLOW, PID_KD_REFLOW);
          // Ramp up to first section of soaking temperature
          setpoint = TEMPERATURE_REFLOW_MAX;
          // Proceed to reflowing state
          reflowState = REFLOW_STATE_REFLOW;
        }
      }
      break;

    case REFLOW_STATE_REFLOW:
      //lcd.clear();
      lcd.setCursor(0, 0);
      lcd.print("Reflowing");
      lcd.setCursor(11, 1);
      lcd.print(input);
      // We need to avoid hovering at peak temperature for too long
      // Crude method that works like a charm and safe for the components
      if (input >= (TEMPERATURE_REFLOW_MAX - 5.0))
      {
        // Set PID parameters for cooling ramp
        reflowOvenPID.SetTunings(PID_KP_REFLOW, PID_KI_REFLOW, PID_KD_REFLOW);
        // Ramp down to minimum cooling temperature
        setpoint = TEMPERATURE_COOL;
        // Proceed to cooling state
        reflowState = REFLOW_STATE_COOL;

        // Turn Elements Off
        digitalWrite(HeaterPin, LOW);

        // Signal to Open Door
        //for (int i = 0; i<10;i++){
        //  tone(BuzPin,4100,100); //Buzz the Buzzer
        //  delay(250);
        //}

      }
      break;

    case REFLOW_STATE_COOL:
      //lcd.clear();
      lcd.setCursor(0, 0);
      lcd.print("Cooling");
      lcd.setCursor(11, 1);
      lcd.print(input);
      // If minimum cool temperature is achieve
      if (input <= TEMPERATURE_COOL)
      {
        // Retrieve current time for buzzer usage
        buzzerPeriod = millis() + 1000;

        //for (int i = 0; i<10;i++){
        //  tone(BuzPin,4100,500); //Buzz the Buzzer
        //  delay(250);
        //}

        reflowStatus = REFLOW_STATUS_OFF;
        // Proceed to reflow Completion state
        reflowState = REFLOW_STATE_COMPLETE;
      }
      break;

    case REFLOW_STATE_COMPLETE:
      //lcd.clear();
      lcd.setCursor(0, 0);
      lcd.print("Reflow Done");
      lcd.setCursor(11, 1);
      lcd.print(input);
      if (millis() > buzzerPeriod)
      {
        reflowState = REFLOW_STATE_IDLE;
      }
      break;

    case REFLOW_STATE_TOO_HOT:
      // If oven temperature drops below room temperature
      if (input < TEMPERATURE_COOL)
      {
        // Ready to reflow
        reflowState = REFLOW_STATE_IDLE;
      }
      break;

    case REFLOW_STATE_ERROR:
      //lcd.clear();
      lcd.setCursor(0, 0);
      lcd.print("Reflow Error");
      lcd.setCursor(11, 1);
      lcd.print(input);
      // If thermocouple problem is still present
      if (isnan(input))
      {
        // Wait until thermocouple wire is connected
        reflowState = REFLOW_STATE_ERROR;
      }
      else
      {
        // Clear to perform reflow process
        reflowState = REFLOW_STATE_IDLE;
      }
      break;

    case REFLOW_STATE_ABORT:
      //lcd.clear();
      lcd.setCursor(0, 0);
      lcd.print("Abort");
      lcd.setCursor(11, 1);
      lcd.print(input);
      Serial.println("Abort!");
      StartTest = false;
      reflowStatus = REFLOW_STATUS_OFF;
      reflowState = REFLOW_STATE_IDLE;
      break;
  }

  // PID computation and SSR control
  if (reflowStatus == REFLOW_STATUS_ON)
  {
    now = millis();

    reflowOvenPID.Compute();
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

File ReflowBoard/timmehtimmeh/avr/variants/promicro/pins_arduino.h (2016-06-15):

/*
  pins_arduino.h - Pin definition functions for Arduino
  Part of Arduino - http://www.arduino.cc/

  Copyright (c) 2007 David A. Mellis

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
  $Id: wiring.h 249 2007-02-03 16:52:51Z mellis $
*/

#ifndef Pins_Arduino_h
#define Pins_Arduino_h

#include <avr/pgmspace.h>

// Workaround for wrong definitions in "iom32u4.h".
// This should be fixed in the AVR toolchain.
#undef UHCON
#undef UHINT
#undef UHIEN
#undef UHADDR
#undef UHFNUM
#undef UHFNUML
#undef UHFNUMH
#undef UHFLEN
#undef UPINRQX
#undef UPINTX
#undef UPNUM
#undef UPRST
#undef UPCONX
#undef UPCFG0X
#undef UPCFG1X
#undef UPSTAX
#undef UPCFG2X
#undef UPIENX
#undef UPDATX
#undef TCCR2A
#undef WGM20
#undef WGM21
#undef COM2B0
#undef COM2B1
#undef COM2A0
#undef COM2A1
#undef TCCR2B
#undef CS20
#undef CS21
#undef CS22
#undef WGM22
#undef FOC2B
#undef FOC2A
#undef TCNT2
#undef TCNT2_0
#undef TCNT2_1
#undef TCNT2_2
#undef TCNT2_3
#undef TCNT2_4
#undef TCNT2_5
#undef TCNT2_6
#undef TCNT2_7
#undef OCR2A
#undef OCR2_0
#undef OCR2_1
#undef OCR2_2
#undef OCR2_3
#undef OCR2_4
#undef OCR2_5
#undef OCR2_6
#undef OCR2_7
#undef OCR2B
#undef OCR2_0
#undef OCR2_1
#undef OCR2_2
#undef OCR2_3
#undef OCR2_4
#undef OCR2_5
#undef OCR2_6
#undef OCR2_7

#define NUM_DIGITAL_PINS  31
#define NUM_ANALOG_INPUTS 12

#define TX_RX_LED_INIT  DDRD |= (1<<5), DDRB |= (1<<0)
#define TXLED0          PORTD |= (1<<5)
#define TXLED1          PORTD &= ~(1<<5)
#define RXLED0          PORTB |= (1<<0)
#define RXLED1          PORTB &= ~(1<<0)

static const uint8_t SDA = 2;
static const uint8_t SCL = 3;
#define LED_BUILTIN 13
#define LED_BUILTIN_RX 17					
#define LED_BUILTIN_TX 30

// Map SPI port to 'new' pins D14..D17
static const uint8_t SS   = 17;
static const uint8_t MOSI = 16;
static const uint8_t MISO = 14;
static const uint8_t SCK  = 15;

// Mapping of analog pins as digital I/O
// A6-A11 share with digital pins
static const uint8_t A0 = 18;
static const uint8_t A1 = 19;
static const uint8_t A2 = 20;
static const uint8_t A3 = 21;
static const uint8_t A4 = 22;
static const uint8_t A5 = 23;
static const uint8_t A6 = 24;   // D4
static const uint8_t A7 = 25;   // D6
static const uint8_t A8 = 26;   // D8
static const uint8_t A9 = 27;   // D9
static const uint8_t A10 = 28;  // D10
static const uint8_t A11 = 29;  // D12

#define digitalPinToPCICR(p)    ((((p) >= 8 && (p) <= 11) || ((p) >= 14 && (p) <= 17) || ((p) >= A8 && (p) <= A10)) ? (&PCICR) : ((uint8_t *)0))
#define digitalPinToPCICRbit(p) 0
#define digitalPinToPCMSK(p)    ((((p) >= 8 && (p) <= 11) || ((p) >= 14 && (p) <= 17) || ((p) >= A8 && (p) <= A10)) ? (&PCMSK0) : ((uint8_t *)0))
#define digitalPinToPCMSKbit(p) ( ((p) >= 8 && (p) <= 11) ? (p) - 4 : ((p) == 14 ? 3 : ((p) == 15 ? 1 : ((p) == 16 ? 2 : ((p) == 17 ? 0 : (p - A8 + 4))))))

//  __AVR_ATmega32U4__ has an unusual mapping of pins to channels
extern const uint8_t PROGMEM analog_pin_to_channel_PGM[];
#define analogPinToChannel(P)  ( pgm_read_byte( analog_pin_to_channel_PGM + (P) ) )

#define digitalPinToInterrupt(p) ((p) == 0 ? 2 : ((p) == 1 ? 3 : ((p) == 2 ? 1 : ((p) == 3 ? 0 : ((p) == 7 ? 4 : NOT_AN_INTERRUPT)))))

#ifdef ARDUINO_MAIN

// On the Arduino board, digital pins are also used
// for the analog output (software PWM).  Analog input
// pins are a separate set.

// ATMEL ATMEGA32U4 / ARDUINO LEONARDO
//
// D0               PD2                 RXD1/INT2
// D1               PD3                 TXD1/INT3
// D2               PD1     SDA         SDA/INT1
// D3#              PD0     PWM8/SCL    OC0B/SCL/INT0
// D4       A6      PD4                 ADC8
// D5#              PC6     ???         OC3A/#OC4A
// D6#      A7      PD7     FastPWM     #OC4D/ADC10
// D7               PE6                 INT6/AIN0
//
// D8       A8      PB4                 ADC11/PCINT4
// D9#      A9      PB5     PWM16       OC1A/#OC4B/ADC12/PCINT5
// D10#     A10     PB6     PWM16       OC1B/0c4B/ADC13/PCINT6
// D11#             PB7     PWM8/16     0C0A/OC1C/#RTS/PCINT7
// D12      A11     PD6                 T1/#OC4D/ADC9
// D13#             PC7     PWM10       CLK0/OC4A
//
// A0       D18     PF7                 ADC7
// A1       D19     PF6                 ADC6
// A2       D20     PF5                 ADC5
// A3       D21     PF4                 ADC4
// A4       D22     PF1                 ADC1
// A5       D23     PF0                 ADC0
//
// New pins D14..D17 to map SPI port to digital pins
//
// MISO     D14     PB3                 MISO,PCINT3
// SCK      D15     PB1                 SCK,PCINT1
// MOSI     D16     PB2                 MOSI,PCINT2
// SS       D17     PB0                 RXLED,SS/PCINT0
//
// Connected LEDs on board for TX and RX
// TXLED    D30     PD5                 XCK1
// RXLED    D17     PB0
// HWB              PE2                 HWB
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

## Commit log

2016-06-29 fixing silkscreen on board for power switch
    [HotplateReflowSchematic.brd]
2016-06-29 Adding schematic for SSR control board. Renaming BOM file to be more obvious
    [SSR_Board.brd, SSR_Board.sch]
2016-06-30 Updating schematic to have automatic switching between USB and DC jack
    [HotplateReflowSchematic.brd, HotplateReflowSchematic.sch]
2016-07-13 Add files via upload
    adding SSR Board Schematic
2016-07-30 Add files via upload
    adding pdf of board layout

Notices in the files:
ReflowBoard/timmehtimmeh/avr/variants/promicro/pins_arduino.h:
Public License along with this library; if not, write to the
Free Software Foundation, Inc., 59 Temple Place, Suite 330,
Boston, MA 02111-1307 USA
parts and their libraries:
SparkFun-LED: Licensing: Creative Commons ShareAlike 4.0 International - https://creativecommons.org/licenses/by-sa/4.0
